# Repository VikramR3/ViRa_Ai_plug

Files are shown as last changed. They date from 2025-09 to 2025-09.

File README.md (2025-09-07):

# ViRa AI Plug

A 2-layer ESP32-S3 mains smart plug: an HLK-5M05 isolated module drops 230 V AC to 5 V, an AMS1117 supplies the ESP32-S3-WROOM-1, and an SRD-05VDC relay switches the outlet through a low-side AO3400A MOSFET with a flyback diode and status LED. A DS3231M with a CR1220 backup cell keeps time for scheduled switching, with six buttons and a buzzer for local control and USB-C for programming. Designed in KiCad 10.

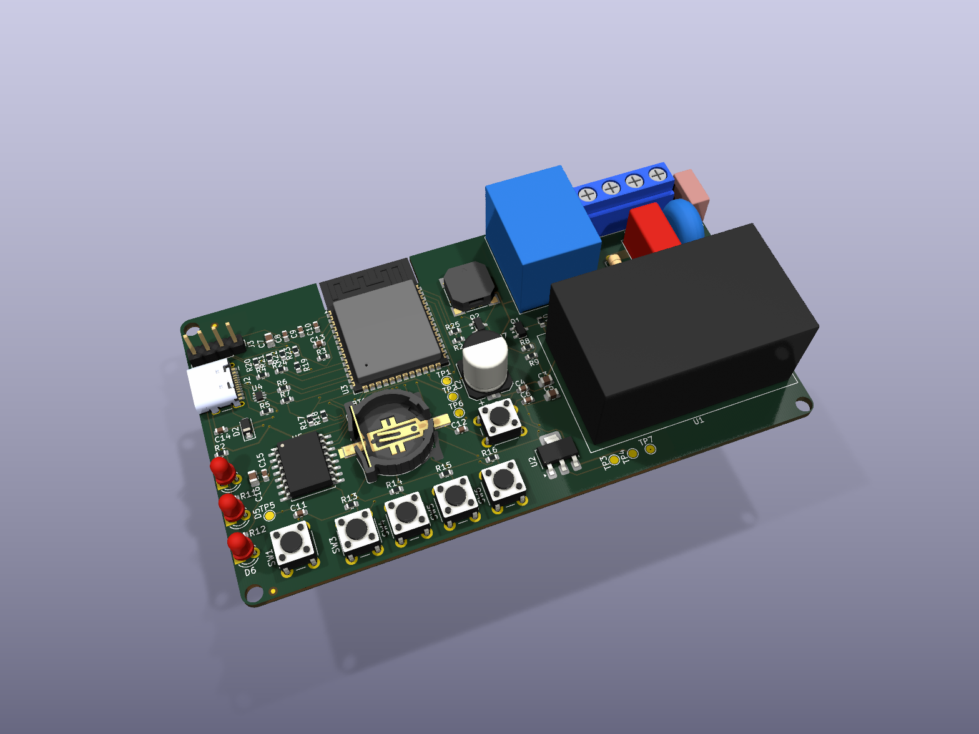
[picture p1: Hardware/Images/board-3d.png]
Board


## Warning — mains voltage

This board carries 230 V AC. The mains and low-voltage sections are separated by a documented barrier — 6.78 mm of creepage in the open board area, enforced by `ViRa_V1.0.kicad_dru`. However the tightest mains-to-low-voltage gap is **2.10 mm**, at the relay's mains common pad, which is below the 2.5 mm functional minimum and needs the relay or the power module re-placed to fix. It has not been fabricated or tested. Do not connect it to mains.

Circuit topology follows the open-source Zeen-AI-Plug smart plug.

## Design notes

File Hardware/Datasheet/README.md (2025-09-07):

# Datasheets

Vendor documents for the parts used on ViRa_V1.0. These are the manufacturers'
own PDFs — download them from source rather than committing copies taken from
another project's repository.

| Part | Ref | Where |
|---|---|---|
| ESP32-S3-WROOM-1 | U3 | espressif.com — `esp32-s3-wroom-1_wroom-1u_datasheet_en.pdf` |
| HLK-5M05 (230 Vac → 5 V, 5 W) | U1 | hlktech.net |
| AMS1117-3.3 | U2 | Advanced Monolithic Systems |
| DS3231M RTC | U5 | analog.com |
| SRD-05VDC-SL-C relay | K2 | Songle — check coil resistance and contact rating |
| MLT-8530 buzzer | LS1 | see `../External_Libraries/ul_MLT-8530/` |
| CH291-1220LF cell holder | BT1 | see `../External_Libraries/CH291-1220LF/` |
| AO3400A N-MOSFET | Q1, Q2 | Alpha & Omega |
| USBLC6-2P6 ESD | U4 | st.com |

The two that matter most for this board: the **SRD-05VDC coil current** (sets the
AO3400A gate drive and the 5 V budget) and the **HLK-5M05 output rating** (1 A,
which is what the +5V copper is sized against).

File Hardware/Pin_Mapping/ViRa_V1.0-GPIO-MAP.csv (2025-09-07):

Pin | Pin name | GPIO | Net
1 | GND |  | GND
2 | 3V3 |  | +3.3V
3 | EN |  | CHIP-PU/RST/EN
4 | IO4 | GPIO4 | SL/I04
5 | IO5 | GPIO5 | (unconnected)
6 | IO6 | GPIO6 | (unconnected)
7 | IO7 | GPIO7 | (unconnected)
8 | IO15 | GPIO15 | (unconnected)
9 | IO16 | GPIO16 | (unconnected)
10 | IO17 | GPIO17 | SDA2/IO17
11 | IO18 | GPIO18 | SCL2/IO18
12 | IO8 | GPIO8 | SDA/IO8
13 | USB_D- |  | USB_D-
14 | USB_D+ |  | USB_D+
15 | IO3 | GPIO3 | EL/IO3
16 | IO46 | GPIO46 | (unconnected)
17 | IO9 | GPIO9 | SCL/IO9
18 | IO10 | GPIO10 | (unconnected)
19 | IO11 | GPIO11 | SW1/IO11
20 | IO12 | GPIO12 | SW2/IO12
21 | IO13 | GPIO13 | SW3/IO13
22 | IO14 | GPIO14 | SW4/IO14
23 | IO21 | GPIO21 | (unconnected)
24 | IO47 | GPIO47 | (unconnected)
25 | IO48 | GPIO48 | (unconnected)
26 | IO45 | GPIO45 | (unconnected)
27 | IO0 | GPIO0 | BOOT
28 | IO35 | GPIO35 | (unconnected)
29 | IO36 | GPIO36 | (unconnected)
30 | IO37 | GPIO37 | (unconnected)
31 | IO38 | GPIO38 | (unconnected)
32 | IO39 | GPIO39 | (unconnected)
33 | IO40 | GPIO40 | (unconnected)
34 | IO41 | GPIO41 | (unconnected)
35 | IO42 | GPIO42 | (unconnected)
36 | RXD0 |  | Net-(U3-RXD0)
37 | TXD0 |  | Net-(U3-TXD0)
38 | IO2 | GPIO2 | RELAY/IO2
39 | IO1 | GPIO1 | BUZZ/IO1
40 | GND |  | GND
41 | GND |  | GND

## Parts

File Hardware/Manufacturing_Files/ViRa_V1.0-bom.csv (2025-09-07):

Refs | Value | Footprint | Qty | DNP
BT1 | CH291-1220LF | CH291-1220LF:BAT_CH291-1220LF | 1
C1 | 0.1uF | Capacitor_THT:C_Rect_L13.0mm_W6.0mm_P10.00mm_FKS3_FKP3_MKS4 | 1
C2 | 220uF | Capacitor_SMD:CP_Elec_8x10 | 1
C3 | 10uF | Capacitor_SMD:C_0805_2012Metric | 1
C4 | 0.1uF | Capacitor_SMD:C_0603_1608Metric | 1
C5 | 10uF | Capacitor_SMD:C_0805_2012Metric | 1
C6 | 0.1uF | Capacitor_SMD:C_0603_1608Metric | 1
C7 | 10uF | Capacitor_SMD:C_0805_2012Metric | 1
C8 | 0.1uF | Capacitor_SMD:C_0603_1608Metric | 1
C9 | 0.1uF | Capacitor_SMD:C_0603_1608Metric | 1
C10 | 0.1uF | Capacitor_SMD:C_0603_1608Metric | 1
C11 | 0.1uF | Capacitor_SMD:C_0603_1608Metric | 1
C12 | 0.1uF | Capacitor_SMD:C_0603_1608Metric | 1
C13 | 0.1uF | Capacitor_SMD:C_0603_1608Metric | 1
C14 | 0.1uF | Capacitor_SMD:C_0603_1608Metric | 1
C15 | 0.1uF | Capacitor_SMD:C_0603_1608Metric | 1
C16 | 2.2uF | Capacitor_SMD:C_0805_2012Metric | 1
D1 | RED | LED_THT:LED_D3.0mm | 1
D2 | MBR0520 | Diode_SMD:D_SOD-123 | 1
D3 | 1N4148W | Diode_SMD:D_SOD-123 | 1
D4 | RED | LED_SMD:LED_0603_1608Metric | 1
D5 | GREEN | LED_THT:LED_D3.0mm | 1
D6 | YELLOW | LED_THT:LED_D3.0mm | 1
D7 | 1N4148W | Diode_SMD:D_SOD-123 | 1
F1 | 500mA 250V | Fuse:Fuse_Littelfuse_395Series | 1
J1 | Screw_Terminal_01x04 | TerminalBlock:TerminalBlock_MaiXu_MX126-5.0-04P_1x04_P5.00mm | 1
J2 | USB_C_Receptacle_USB2.0_16P | Connector_USB:USB_C_Receptacle_HCTL_HC-TYPE-C-16P-01A | 1
J3 | Conn_01x04_Pin | Connector_PinHeader_2.54mm:PinHeader_1x04_P2.54mm_Vertical | 1
K2 | SANYOU_SRD_Form_C | Relay_THT:Relay_SPDT_SANYOU_SRD_Series_Form_C | 1
LS1 | MLT-8530 | footprints:MLT-8530_JHE | 1
Q1 | AO3400A | Package_TO_SOT_SMD:SOT-23 | 1
Q2 | AO3400A | Package_TO_SOT_SMD:SOT-23 | 1
R1 | 1M | Resistor_THT:R_Axial_DIN0207_L6.3mm_D2.5mm_P7.62mm_Horizontal | 1
R2 | 4K7 | Resistor_SMD:R_0603_1608Metric | 1
R3 | 10K | Resistor_SMD:R_0603_1608Metric | 1
R4 | 5K1 | Resistor_SMD:R_0603_1608Metric | 1
R5 | 5K1 | Resistor_SMD:R_0603_1608Metric | 1
R6 | 0R | Resistor_SMD:R_0603_1608Metric | 1
R7 | 0R | Resistor_SMD:R_0603_1608Metric | 1
R8 | 1K | Resistor_SMD:R_0603_1608Metric | 1
R9 | 10K | Resistor_SMD:R_0603_1608Metric | 1
R10 | 1K | Resistor_SMD:R_0603_1608Metric | 1
R11 | 1K | Resistor_SMD:R_0603_1608Metric | 1
R12 | 1K | Resistor_SMD:R_0603_1608Metric | 1
R13 | 10K | Resistor_SMD:R_0603_1608Metric | 1
R14 | 10K | Resistor_SMD:R_0603_1608Metric | 1
R15 | 10K | Resistor_SMD:R_0603_1608Metric | 1
R16 | 10K | Resistor_SMD:R_0603_1608Metric | 1
R17 | 10K | Resistor_SMD:R_0603_1608Metric | 1
R18 | 10K | Resistor_SMD:R_0603_1608Metric | 1
R19 | 0R | Resistor_SMD:R_0603_1608Metric | 1
R20 | 0R | Resistor_SMD:R_0603_1608Metric | 1
R21 | 10K | Resistor_SMD:R_0603_1608Metric | 1
R22 | 10K | Resistor_SMD:R_0603_1608Metric | 1
R23 | 0R | Resistor_SMD:R_0603_1608Metric | 1
R24 | 0R | Resistor_SMD:R_0603_1608Metric | 1
R25 | 10K | Resistor_SMD:R_0603_1608Metric | 1
R26 | 1K | Resistor_SMD:R_0603_1608Metric | 1
RV1 | 10D56K | Varistor:RV_Disc_D12mm_W5mm_P7.5mm | 1
SW1 | SW_Push | Button_Switch_THT:SW_PUSH_6mm | 1
SW2 | SW_Push | Button_Switch_THT:SW_PUSH_6mm | 1
SW3 | SW_Push | Button_Switch_THT:SW_PUSH_6mm | 1
SW4 | SW_Push | Button_Switch_THT:SW_PUSH_6mm | 1
SW5 | SW_Push | Button_Switch_THT:SW_PUSH_6mm | 1
SW6 | SW_Push | Button_Switch_THT:SW_PUSH_6mm | 1
TP1 | TXD0 | TestPoint:TestPoint_Pad_D1.5mm | 1
TP2 | RXD0 | TestPoint:TestPoint_Pad_D1.5mm | 1
TP3 | 3V3 | TestPoint:TestPoint_Pad_D1.5mm | 1
TP4 | 5V | TestPoint:TestPoint_Pad_D1.5mm | 1
TP5 | EN | TestPoint:TestPoint_Pad_D1.5mm | 1
TP6 | BOOT | TestPoint:TestPoint_Pad_D1.5mm | 1
TP7 | GND | TestPoint:TestPoint_Pad_D1.5mm | 1
U1 | HLK-5M05 | Converter_ACDC:Converter_ACDC_Hi-Link_HLK-5Mxx | 1
U2 | AMS1117-3.3 | Package_TO_SOT_SMD:SOT-223-3_TabPin2 | 1
U3 | ESP32-S3-WROOM-1 | RF_Module:ESP32-S3-WROOM-1 | 1
U4 | USBLC6-2P6 | Package_TO_SOT_SMD:SOT-666 | 1
U5 | DS3231M | Package_SO:SOIC-16W_7.5x10.3mm_P1.27mm | 1

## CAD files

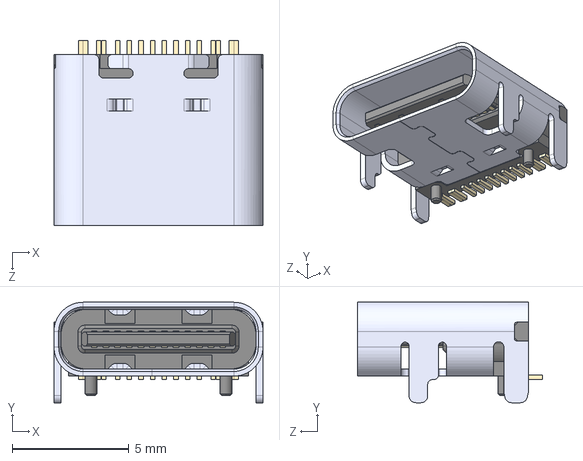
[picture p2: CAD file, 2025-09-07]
Hardware/External_3D_Models/TYPE-C-31-M-12--3DModel-STEP-56544.STEP
8.94 x 4.30 x 7.90 mm

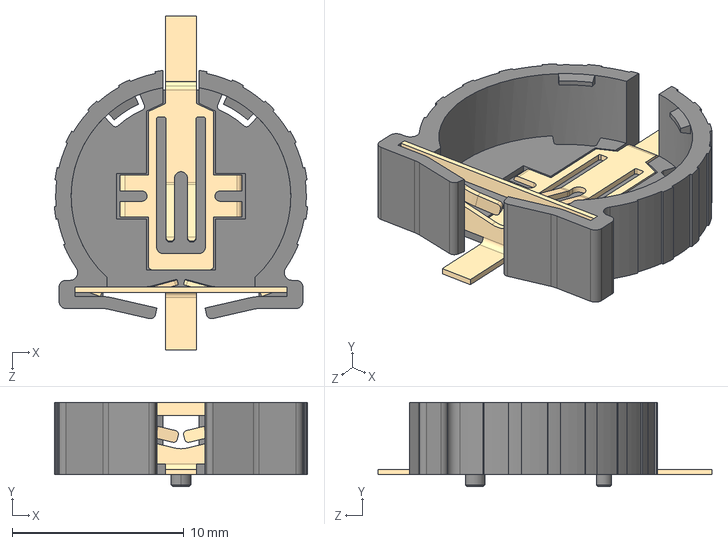
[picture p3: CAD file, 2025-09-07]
Hardware/External_Libraries/CH291-1220LF/CH291-1220LF.step
14.7 x 4.90 x 19.4 mm

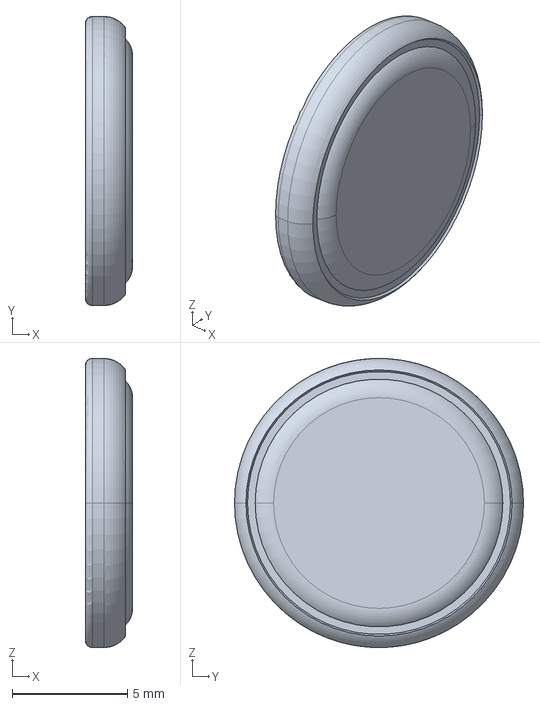
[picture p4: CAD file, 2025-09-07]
Hardware/External_3D_Models/k_cr1220_lithium-cell.stp
2.05 x 12.6 x 12.5 mm

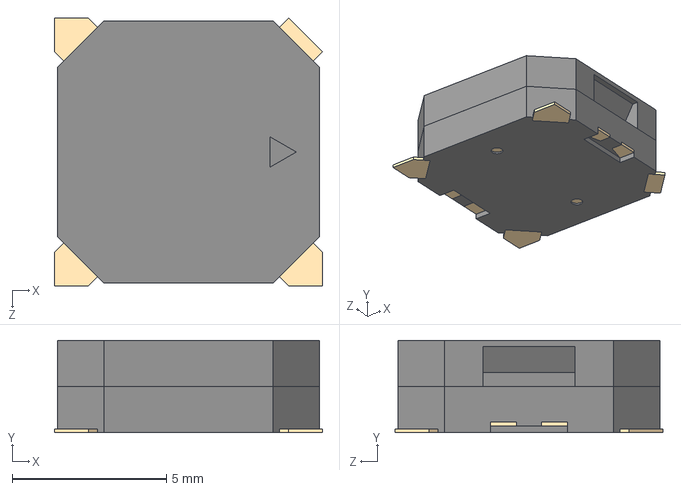
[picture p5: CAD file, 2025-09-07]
Hardware/External_3D_Models/MLT-8530--3DModel-STEP-269445.STEP
8.70 x 3.00 x 8.70 mm

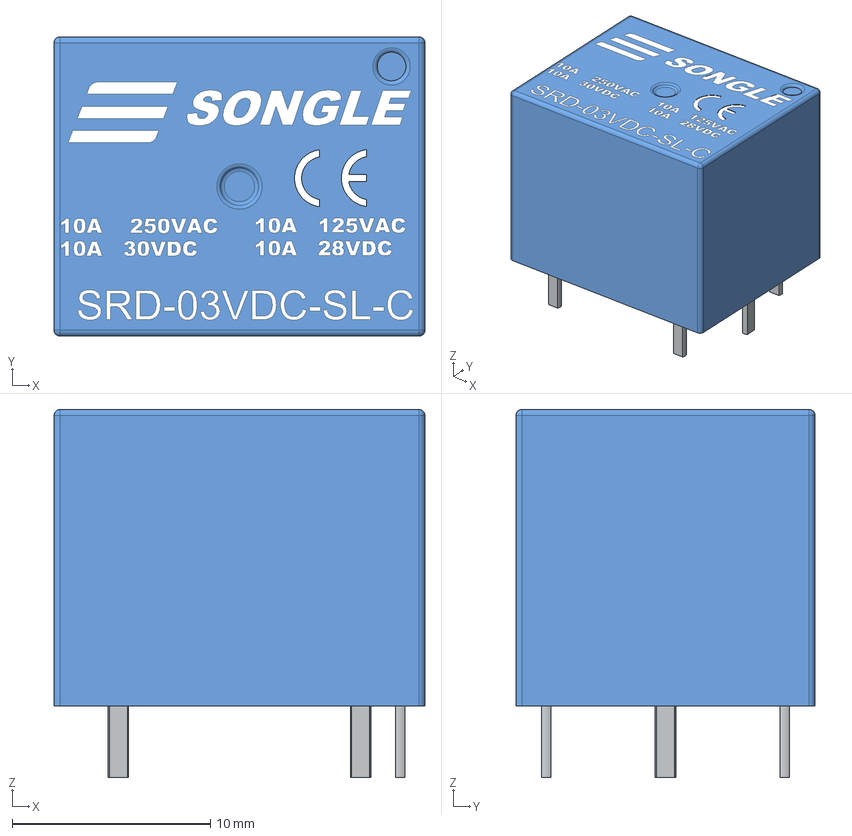
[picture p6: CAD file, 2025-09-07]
Hardware/External_3D_Models/Relay - SRD-03VDC-SL-C.stp
18.7 x 15.1 x 18.6 mm

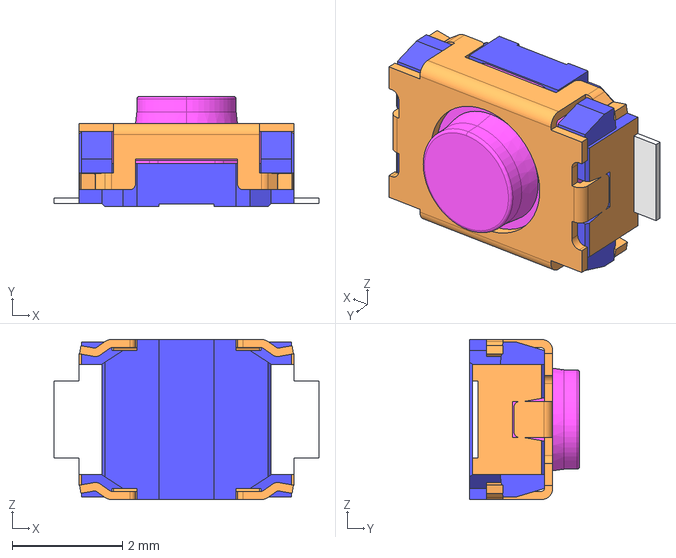
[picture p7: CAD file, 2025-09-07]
Hardware/External_3D_Models/skrkaee010.stp
4.80 x 2.00 x 2.90 mm

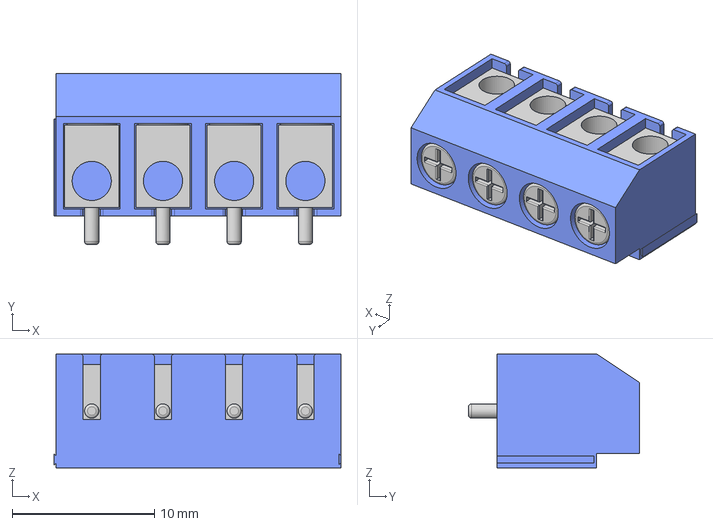
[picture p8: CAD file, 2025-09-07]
Hardware/External_3D_Models/Screw Terminal Block 5mm Blue 4-way.step
20.1 x 12.0 x 8.00 mm

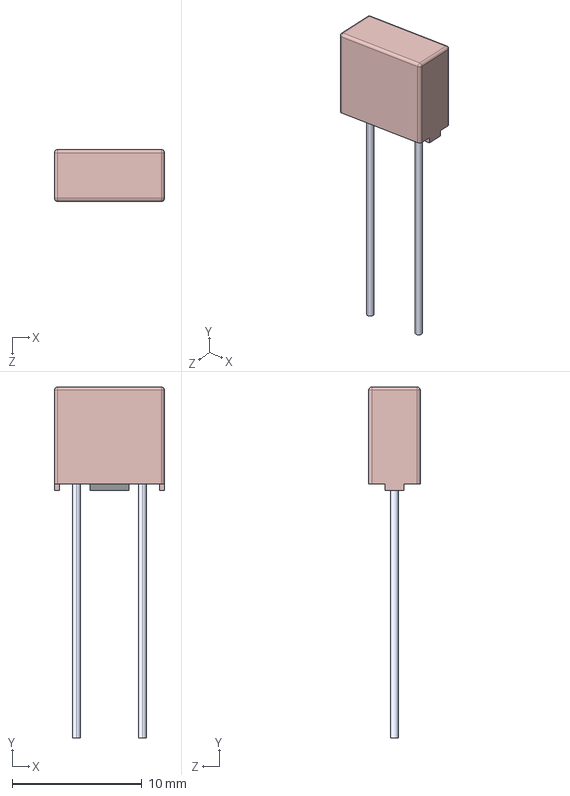
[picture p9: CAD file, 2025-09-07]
Hardware/External_3D_Models/39208000000.STEP
8.50 x 27.1 x 4.00 mm

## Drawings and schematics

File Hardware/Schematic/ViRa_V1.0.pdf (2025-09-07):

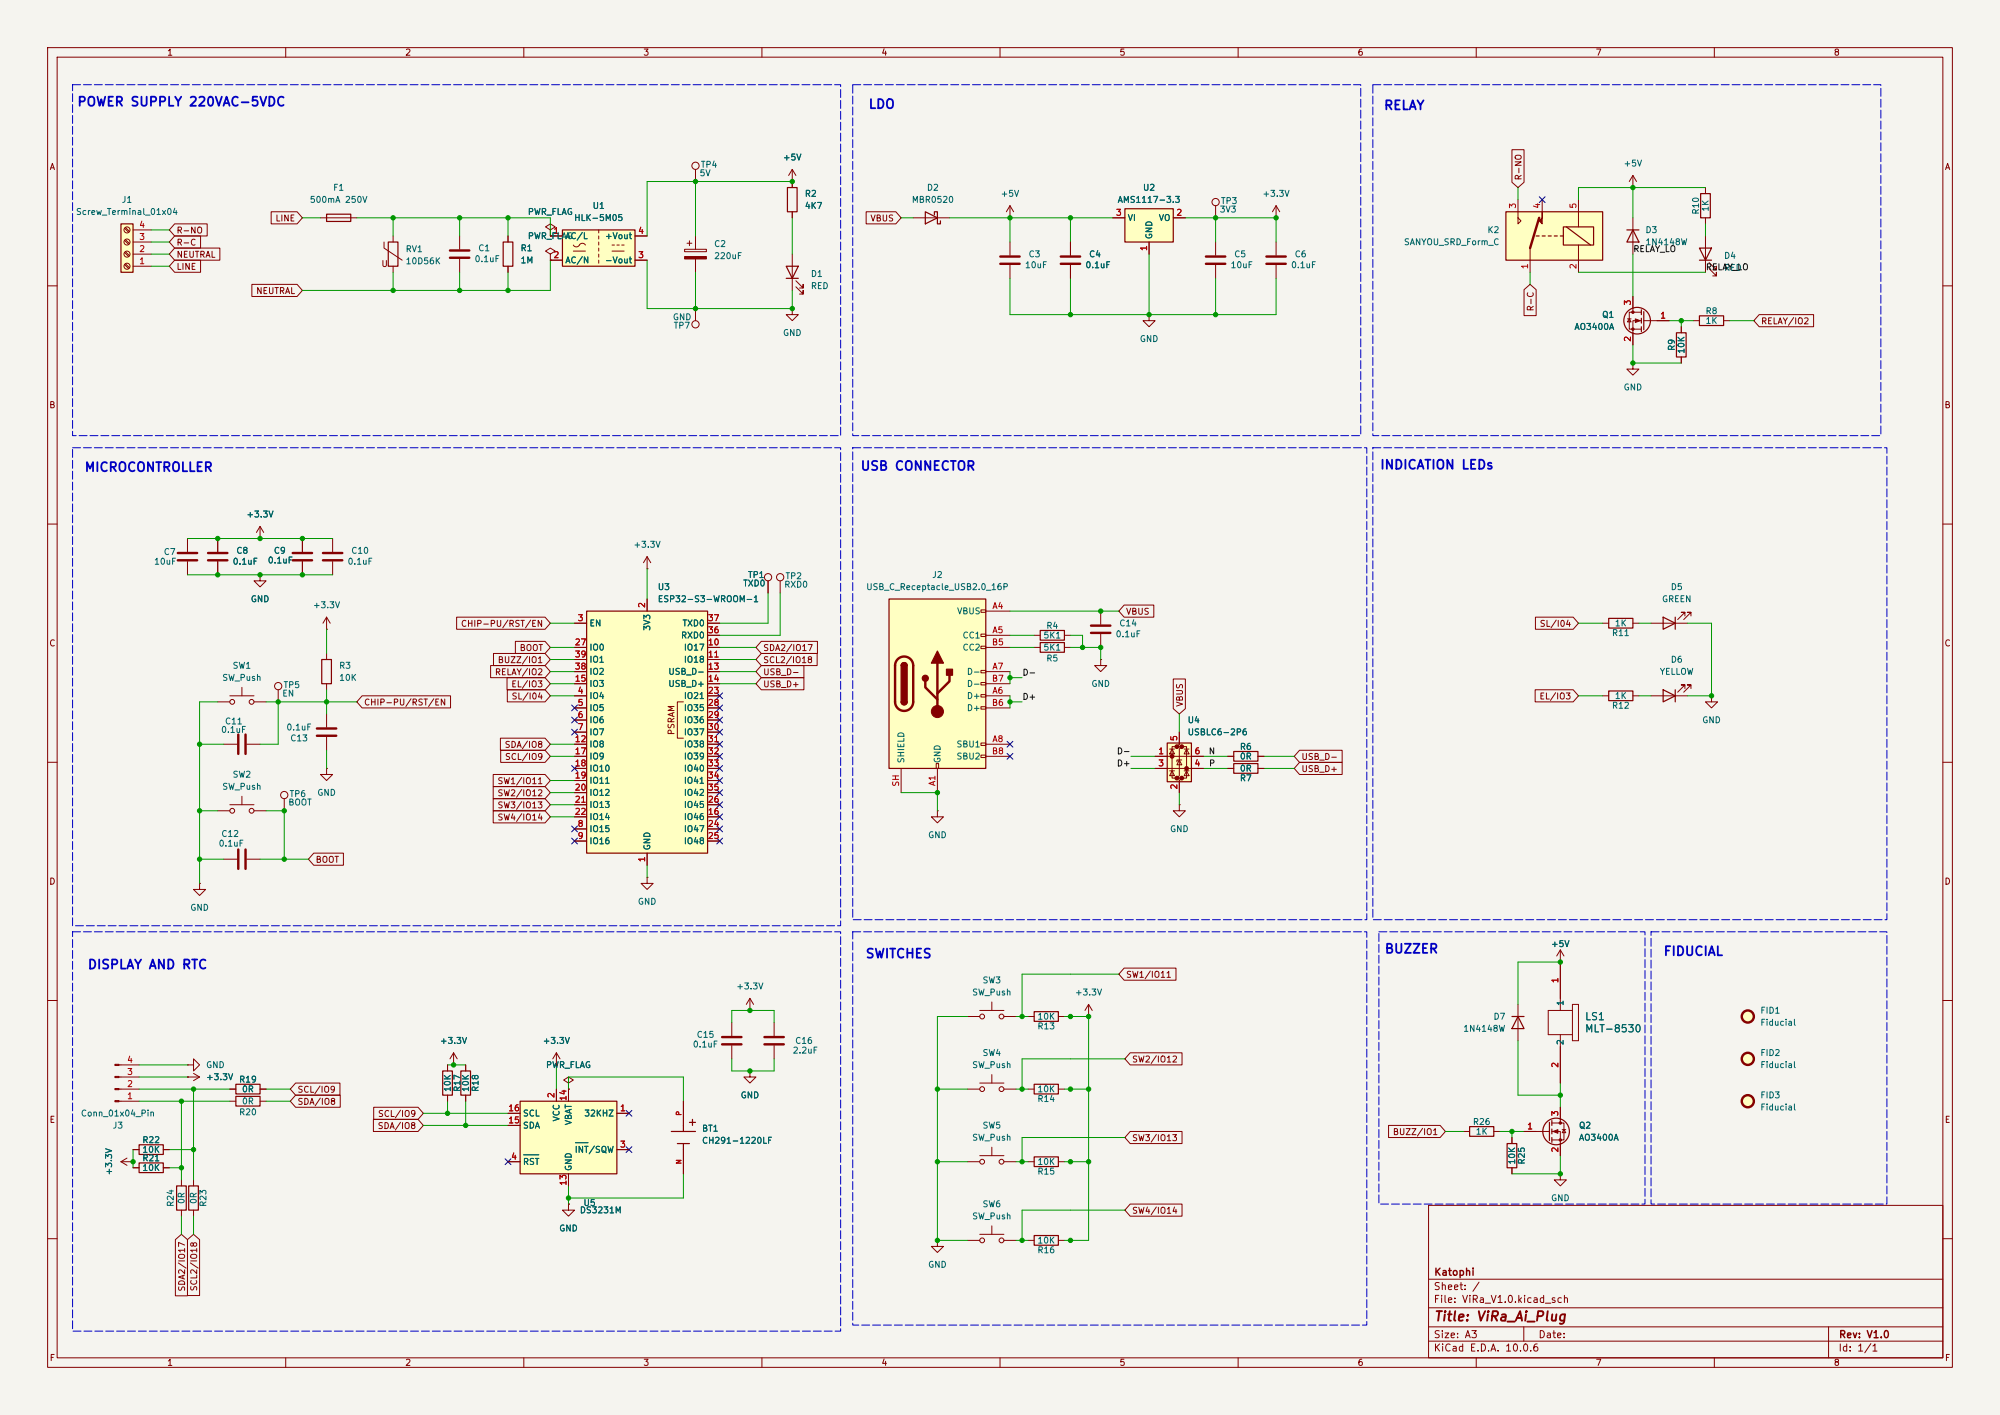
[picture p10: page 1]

CHIP-PU/RST/EN

Size: A3 | Rev: V1.0 | F Date:
KiCad E.D.A. 10.0.6 | Id: 1/1

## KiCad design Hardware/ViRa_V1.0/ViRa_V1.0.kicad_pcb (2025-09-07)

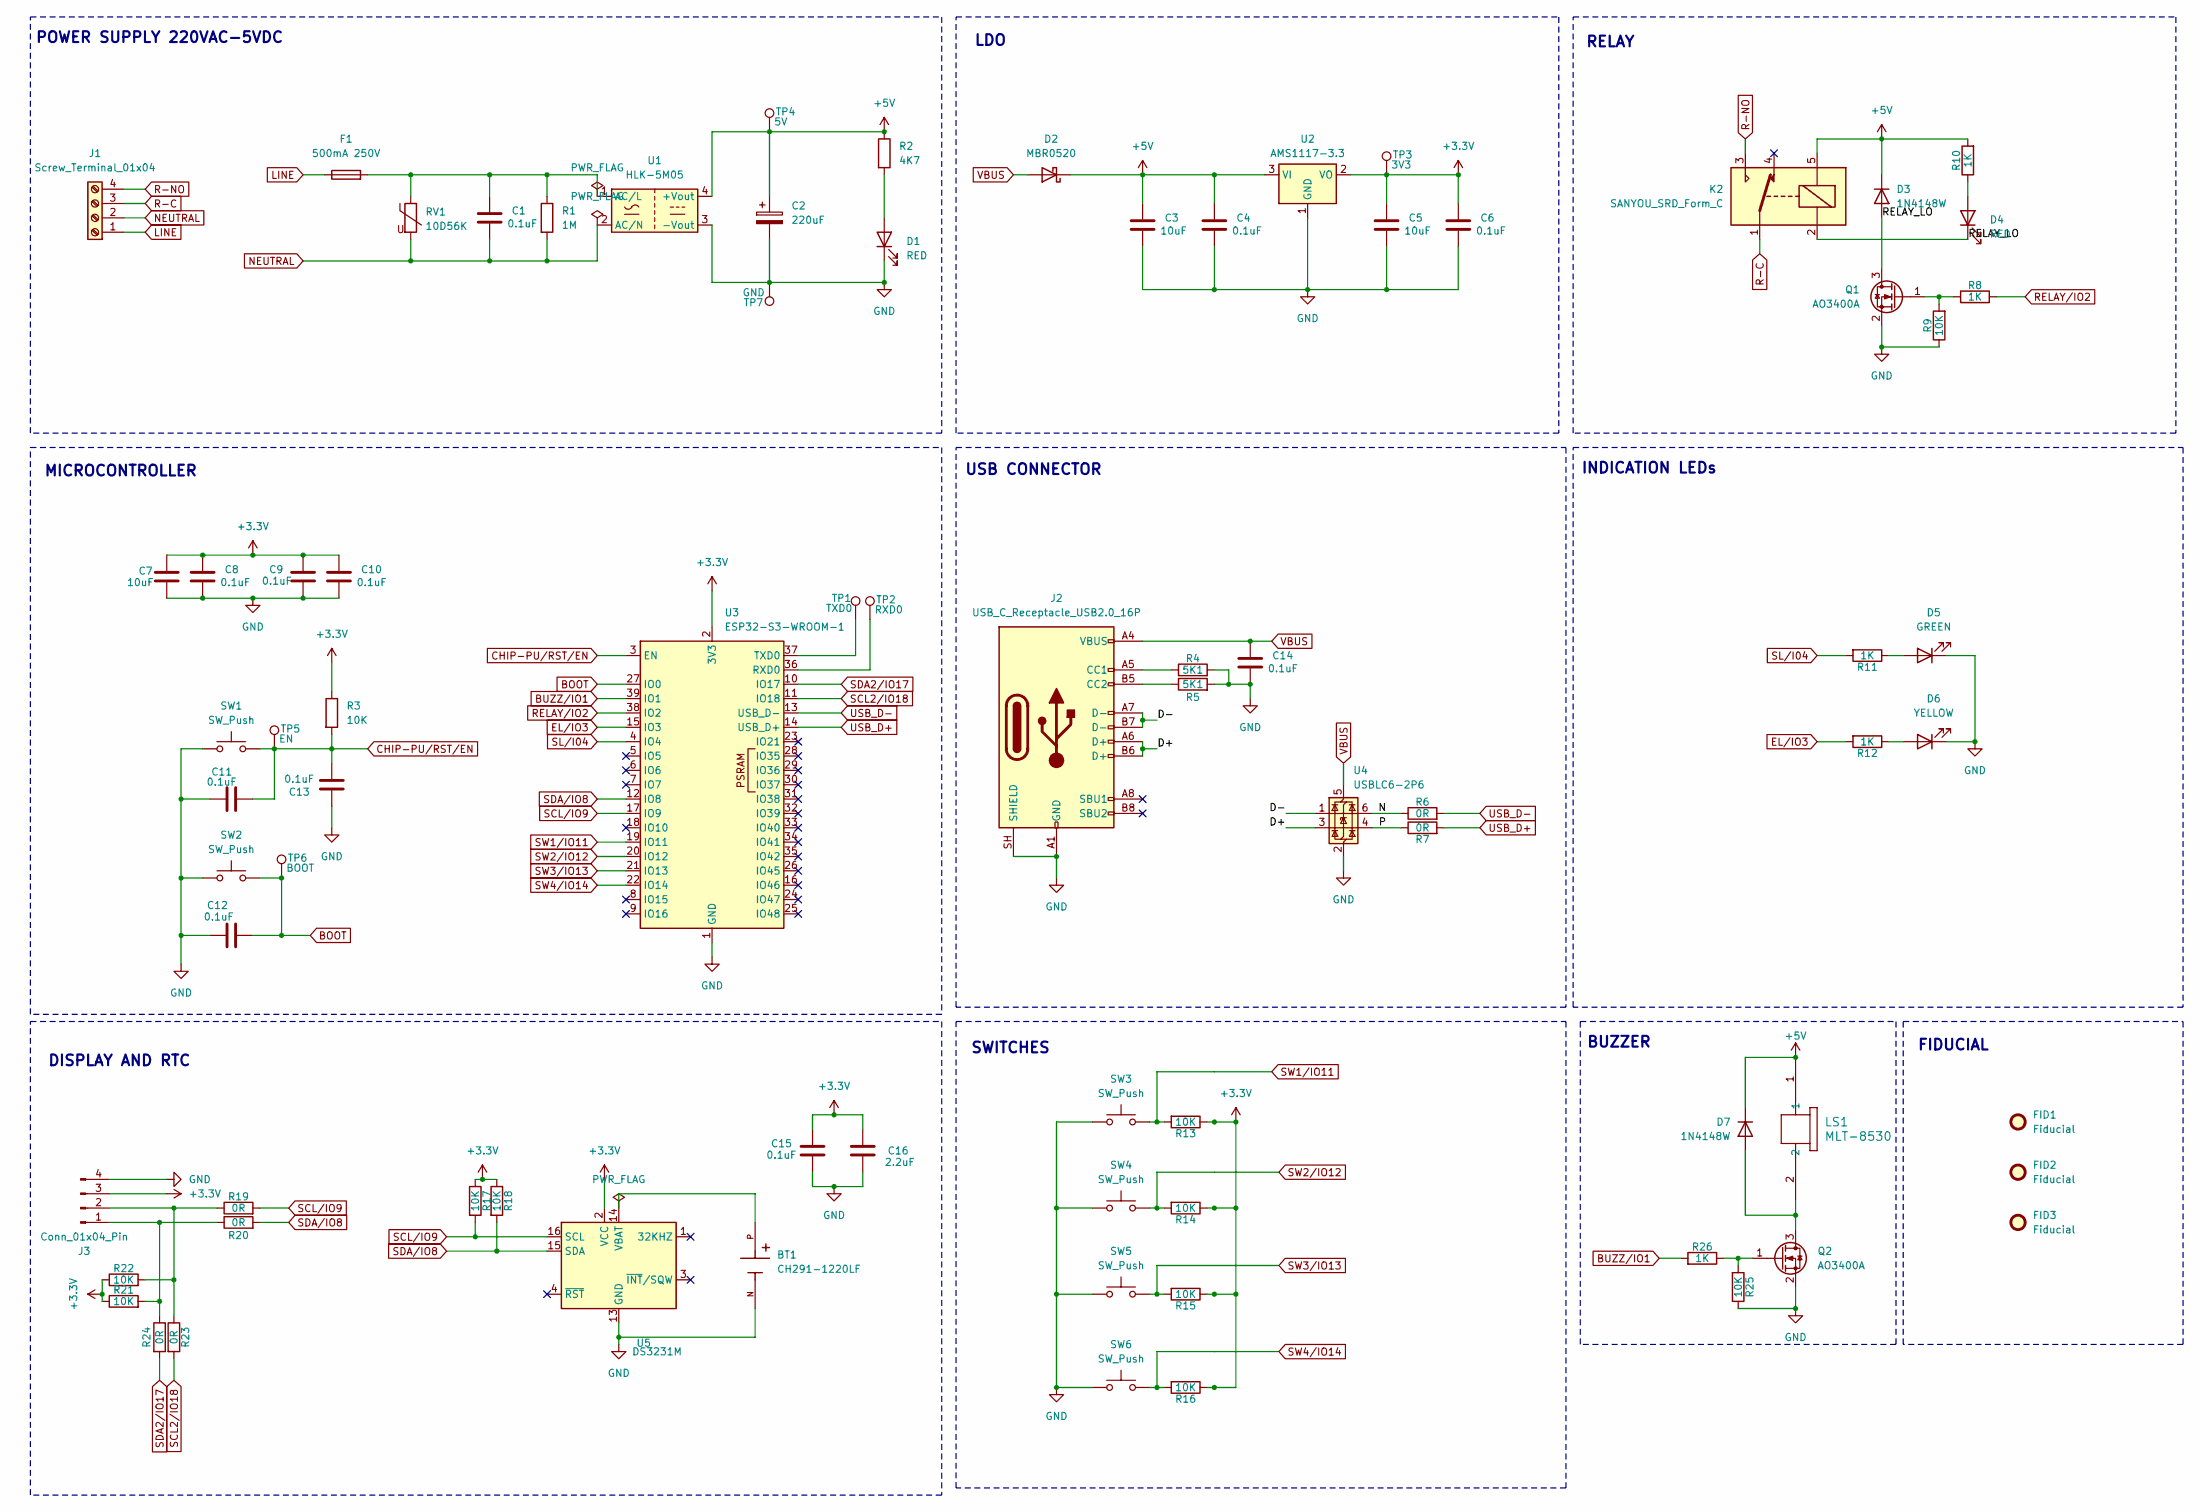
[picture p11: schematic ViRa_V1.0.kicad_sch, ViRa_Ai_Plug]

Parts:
BT1: CH291-1220LF; BAT_CH291-1220LF; PARTREV A
C1: 0.1uF; C_Rect_L13.0mm_W6.0mm_P10.00mm_FKS3_FKP3_MKS4
C2: 220uF; CP_Elec_8x10
C3, C5, C7: 10uF; C_0805_2012Metric
C4, C6, C8, C9, C10, C11, C12, C13, C14, C15: 0.1uF; C_0603_1608Metric
C16: 2.2uF; C_0805_2012Metric
D1: RED; LED_D3.0mm
D2: MBR0520; D_SOD-123
D3, D7: 1N4148W; D_SOD-123
D4: RED; LED_0603_1608Metric
D5: GREEN; LED_D3.0mm
D6: YELLOW; LED_D3.0mm
F1: 500mA 250V; Fuse_Littelfuse_395Series
FID1, FID2, FID3: Fiducial; Fiducial_0.75mm_Mask1.5mm
J1: Screw_Terminal_01x04; TerminalBlock_MaiXu_MX126-5.0-04P_1x04_P5.00mm
J2: USB_C_Receptacle_USB2.0_16P; USB_C_Receptacle_HCTL_HC-TYPE-C-16P-01A
J3: Conn_01x04_Pin; PinHeader_1x04_P2.54mm_Vertical
K2: SANYOU_SRD_Form_C; Relay_SPDT_SANYOU_SRD_Series_Form_C
LS1: MLT-8530; MLT-8530_JHE
Q1, Q2: AO3400A; SOT-23
R1: 1M; R_Axial_DIN0207_L6.3mm_D2.5mm_P7.62mm_Horizontal
R2: 4K7; R_0603_1608Metric
R3, R9, R13, R14, R15, R16, R17, R18, R21, R22, R25: 10K; R_0603_1608Metric
R4, R5: 5K1; R_0603_1608Metric
R6, R7, R19, R20, R23, R24: 0R; R_0603_1608Metric
R8, R10, R11, R12, R26: 1K; R_0603_1608Metric
RV1: 10D56K; RV_Disc_D12mm_W5mm_P7.5mm
SW1, SW2, SW3, SW4, SW5, SW6: SW_Push; SW_PUSH_6mm
TP1: TXD0; TestPoint_Pad_D1.5mm
TP2: RXD0; TestPoint_Pad_D1.5mm
TP3: 3V3; TestPoint_Pad_D1.5mm
TP4: 5V; TestPoint_Pad_D1.5mm
TP5: EN; TestPoint_Pad_D1.5mm
TP6: BOOT; TestPoint_Pad_D1.5mm
TP7: GND; TestPoint_Pad_D1.5mm
U1: HLK-5M05; Converter_ACDC_Hi-Link_HLK-5Mxx
U2: AMS1117-3.3; SOT-223-3_TabPin2
U3: ESP32-S3-WROOM-1
U4: USBLC6-2P6; SOT-666
U5: DS3231M; SOIC-16W_7.5x10.3mm_P1.27mm

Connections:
+3.3V: C5.1, C6.1, C7.1, C8.1, C9.1, C10.1, C15.2, C16.1, J3.3, R3.1, R13.1, R14.1, R15.1, R16.1, R17.1, R18.1, R21.1, R22.1, TP3.1 (1_1), U2.2 (VO), U3.2 (3V3), U5.2 (VCC)
+5V: C2.1, C3.1, C4.1, D2.1 (K), D3.1 (K), D7.1 (K), K2.5, LS1.1, R2.1, R10.2, TP4.1 (1_1), U1.4 (+Vout), U2.3 (VI)
/D+: J2.A6 (D+), J2.B6 (D+), U4.3 (I/O2)
/D-: J2.A7 (D-), J2.B7 (D-), U4.1 (I/O1)
/N: R6.1, U4.6 (I/O1)
/P: R7.1, U4.4 (I/O2)
/RELAY_LO: D3.2 (A), D4.1 (K), K2.2, Q1.3 (D)
BOOT: C12.2, SW2.2, TP6.1 (1_1), U3.27 (IO0)
BUZZ/IO1: R26.2, U3.39 (IO1)
CHIP-PU/RST/EN: C11.2, C13.2, R3.2, SW1.2, TP5.1 (1_1), U3.3 (EN)
EL/IO3: R12.2, U3.15 (IO3)
GND: BT1.N, C2.2, C3.2, C4.2, C5.2, C6.2, C7.2, C8.2, C9.2, C10.2, C11.1, C12.1, C13.1, C14.2, C15.1, C16.2, D1.1 (K), D5.1 (K), D6.1 (K), J2.A1 (GND), J2.A12 (GND), J2.B1 (GND), J2.B12 (GND), J2.SH (SHIELD), J3.4, Q1.2 (S), Q2.2 (S), R4.2, R5.2, R9.1, R25.1, SW1.1, SW2.1, SW3.1, SW4.1, SW5.1, SW6.1, TP7.1 (1_1), U1.3 (-Vout), U2.1 (GND), U3.1 (GND), U3.40 (GND), U3.41 (GND), U4.2 (GND), U5.5 (GND), U5.6 (GND), U5.7 (GND), U5.8 (GND), U5.9 (GND), U5.10 (GND), U5.11 (GND), U5.12 (GND), U5.13 (GND)
LINE: F1.1, J1.1
unnamed: D1.2 (A), R2.2
unnamed: D4.2 (A), R10.1
unnamed: D5.2 (A), R11.1
unnamed: D6.2 (A), R12.1
unnamed: D7.2 (A), LS1.2, Q2.3 (D)
unnamed: J2.A5 (CC1), R4.1
unnamed: J2.B5 (CC2), R5.1
unnamed: J3.1, R20.1, R21.2, R24.1
unnamed: J3.2, R19.1, R22.2, R23.1
unnamed: Q1.1 (G), R8.1, R9.2
unnamed: Q2.1 (G), R25.2, R26.1
unnamed: TP2.1 (1_1), U3.36 (RXD0)
unnamed: TP1.1 (1_1), U3.37 (TXD0)
R-C: J1.3, K2.1
R-NO: J1.4, K2.3
RELAY/IO2: R8.2, U3.38 (IO2)
SCL2/IO18: R23.2, U3.11 (IO18)
SCL/IO9: R17.2, R19.2, U3.17 (IO9), U5.16 (SCL)
SDA2/IO17: R24.2, U3.10 (IO17)
SDA/IO8: R18.2, R20.2, U3.12 (IO8), U5.15 (SDA)
SL/I04: R11.2, U3.4 (IO4)
SW1/IO11: R13.2, SW3.2, U3.19 (IO11)
SW2/IO12: R14.2, SW4.2, U3.20 (IO12)
SW3/IO13: R15.2, SW5.2, U3.21 (IO13)
SW4/IO14: R16.2, SW6.2, U3.22 (IO14)
USB_D+: R7.2, U3.14 (USB_D+)
USB_D-: R6.2, U3.13 (USB_D-)
VBUS: C14.1, D2.2 (A), J2.A4 (VBUS), J2.A9 (VBUS), J2.B4 (VBUS), J2.B9 (VBUS), U4.5 (VBUS)

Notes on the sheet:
FIDUCIAL
DISPLAY AND RTC
USB CONNECTOR
LDO
POWER SUPPLY 220VAC-5VDC
INDICATION LEDs
MICROCONTROLLER
BUZZER
RELAY
SWITCHES

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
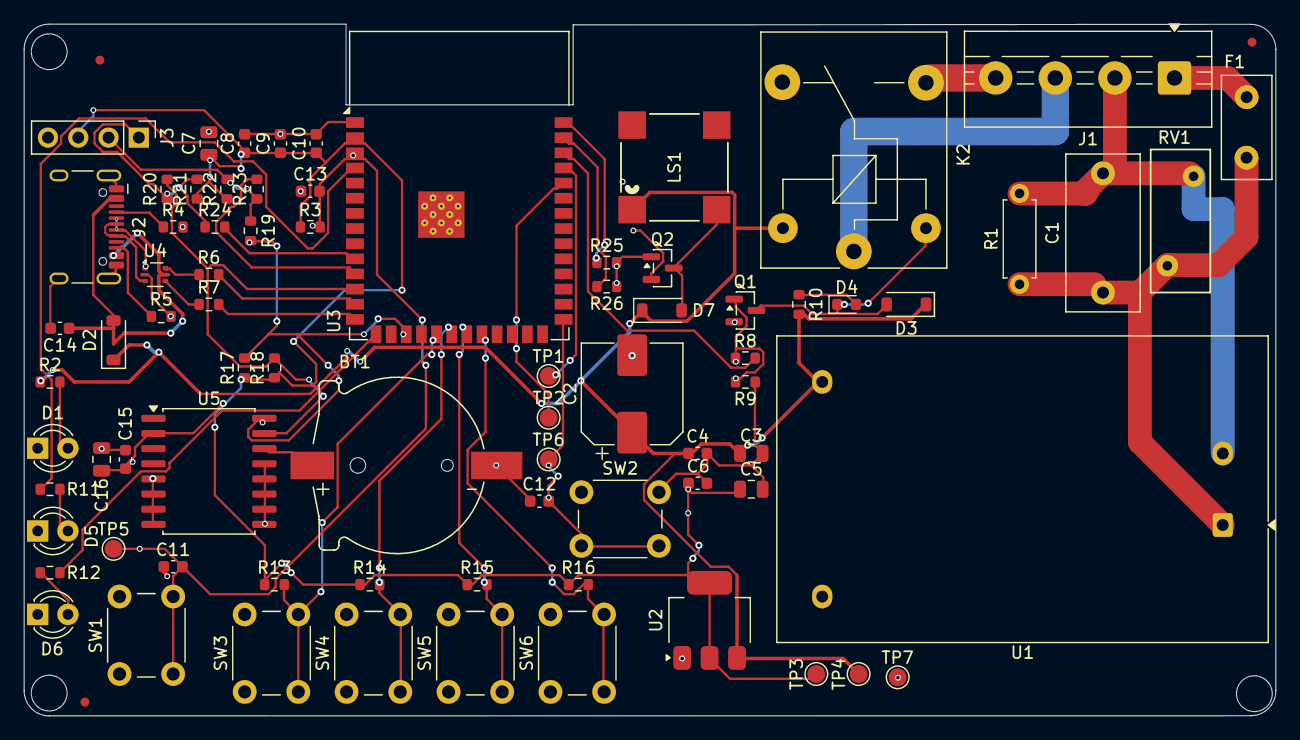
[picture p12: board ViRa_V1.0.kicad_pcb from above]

Board: 2 copper layers, 105.0 x 58.0 mm, 80 parts (0 on the bottom side), 44 nets.

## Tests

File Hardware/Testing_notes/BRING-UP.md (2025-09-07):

# ViRa_V1.0 bring-up checklist

Order matters: prove the low-voltage side works on bench power **before** the
board ever sees mains.

## 1. Bare board, no mains

- [ ] Visual: no solder bridges on U3 / U5 / U2, relay orientation matches silk.
- [ ] Continuity: `GND` to `+5V` and `GND` to 3V3 rail — must **not** be shorted.
- [ ] Mains-to-SELV: confirm no continuity between J1 pads and any low-voltage
      net. This is the isolation barrier; check it before anything else.

## 2. Low-voltage rails, bench supply on the 5 V rail (no mains, U1 not fitted)

- [ ] Inject 5 V at TP4. Measure TP3 = 3.3 V ±5 % (AMS1117 output).
- [ ] Idle current sane (tens of mA, not hundreds).
- [ ] ESP32-S3 enumerates over USB-C; flash a blink sketch.

## 3. Peripherals (still no mains)

- [ ] Buzzer LS1 on GPIO1 — tone.
- [ ] Status LEDs D1/D5/D6.
- [ ] DS3231M over I2C (GPIO8 SDA / GPIO9 SCL) — read time, confirm BT1 keeps it
      across a power cycle.
- [ ] Buttons: SW1 = reset, SW2 = boot. SW3-SW6 read on GPIO11/12/13/14
      respectively (active low, 10k pull-ups R13-R16).
- [ ] Relay: drive GPIO2 high, hear K2 click, confirm continuity J1.3 ↔ J1.4.
      Do this with a multimeter on the contacts, not with a load.

## 4. Mains — only after all the above passes

Do not perform this step without an isolation transformer, an RCD, and
appropriate training. The board has an unresolved 2.10 mm mains-to-SELV gap at
the relay (see the project README); it is not suitable for connection to mains
as built.

## Known issues to check against

- Mains-to-SELV minimum is 2.10 mm at K2's mains COM pad.
